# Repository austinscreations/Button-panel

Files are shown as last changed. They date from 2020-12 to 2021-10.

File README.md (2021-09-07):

# Button-panel
Low cost RGB button panel for home automation - based off superhouse.tv switch setup

After seeing the new RGB switch panels that jon from superhouse.tv is making the thing that has been noted is the switches cost a fair bit of money. 

I thought it might be possible to 3d print parts and use clear acrylic tubing / rod to create low cost versions of teh panels.
To start I've designed two PCB's one has 4 leds per button to emulate teh current ring light buttons
the second version uses one center led for a cenetr lighting in the button - acyrlic rod would be inserted into a 3d print.

Once I have a chance I plan to produce the pcb and order parts on ebay and create the 3d print assemblies to see what teh cost would be and if it works well.

2021-09-07
added a node-red demo taht hsows all the functions nicely.
added to and bottom photos of pcb along with pinout for RX / TX

2021-07-08
Working full code for type-1 assembly has been added. Now has working button deboucing and outputs teh same json type string as the superhouse.tv LSC project.
New PCB's has been produced and is working correctly with new code - files might need to be updated here...

2021-04-28
Added the latest version. will order parts soon to test the design.
Added a new 3d model for an AUS plate, design is incomplete and will get my hands on a real one to adjust the model as needed.

2021-04-23 
added code that will be used during livestream. haven't got tasmota to control the lights correctly yet; thus will be using custom code

2021-04-22
PCB's arrived which means I'll be doing a livestream of their assembly and testing https://youtu.be/Dpo3wsEXy4c

2021-04-18
Updated 3d files to fit around capacitors and ethernet connector. The 3d files and pcb's will be re-layed out to fix these in the next version. allowing for faster 3d printing, vs having holes / cutouts made.

2021-04-16
I've ordered PCB's to test. 
Created 3d photo of pcb assemblies. Next versions will use esp8266 direct vs D1 mini.
Cost Sheet updated.

2020-12-12
reformated files
added new version 2 which makes the pcb compact - allows for 24mm spacing between each button matching the assembly of teh superhouse button panels - it allso allowed for teh buttons to be centered on a wall plate. wall plate is normal cover / size for single gang north america box
3D step files for each button design assembly has been added - these are untested - no parts on order yet.
future possible version my have the 0.1mm pitch conenctor to match up to the new superhouse tv RGB button assembly.

2020-12-04
updating pcb files as the 1000uf capacitor was the wrong size (footprint is now 10x10mm)
adding photos of the pcb for both versions
added parts list for both versions
added rough cost breakdown of buying parts on ebay

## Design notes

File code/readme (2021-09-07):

code for v3 button panel

working code is available for type 1 button panel - has the ring lights
buttons and LEDs work on 1-based numbering.

MQTT information:
 *  option - set color    (topic = %hostname%/color; payload = led#, R,G,B,W (0-255))
 *  option fade to color  (topic = %hostname%/fade;  payload = led#, R,G,B,W (0-255))
 *  option ring           (topic = %hostname%/ring;  payload = led#, #ON, R,G,B,W (0-255))
 *  option FWD animation  (topic = %hostname%/fwd;   payload = led#, R,G,B,W,R2,G2,B2,W2,  (0-255))
 *  option BWD animation  (topic = %hostname%/bwd;   payload = led#, R,G,B,W,R2,G2,B2,W2,  (0-255))
 *
 *  button press = button # and state output on topic %hostname%/button
 *  
 *  online status can be found with %hostname%/LWT

node red demo will require node-red-contrib-countdown : countdown (there are two, i used the first one, non #2)

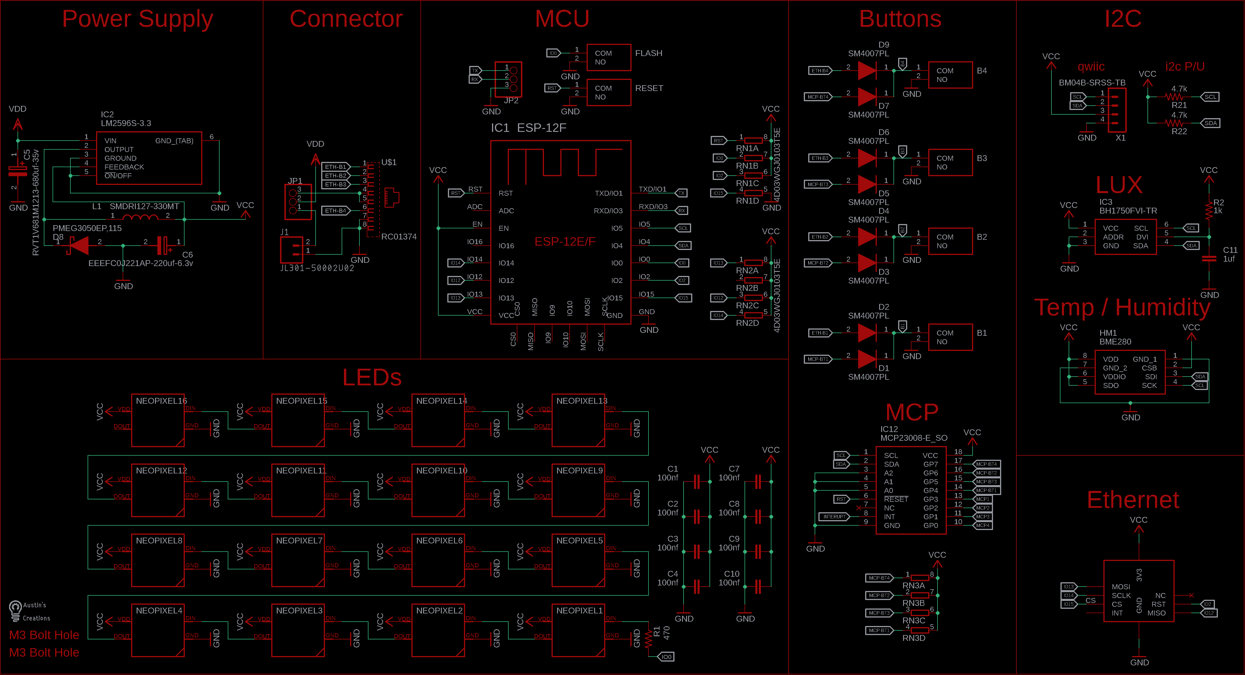
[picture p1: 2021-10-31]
version 4/type-1/schematic.png

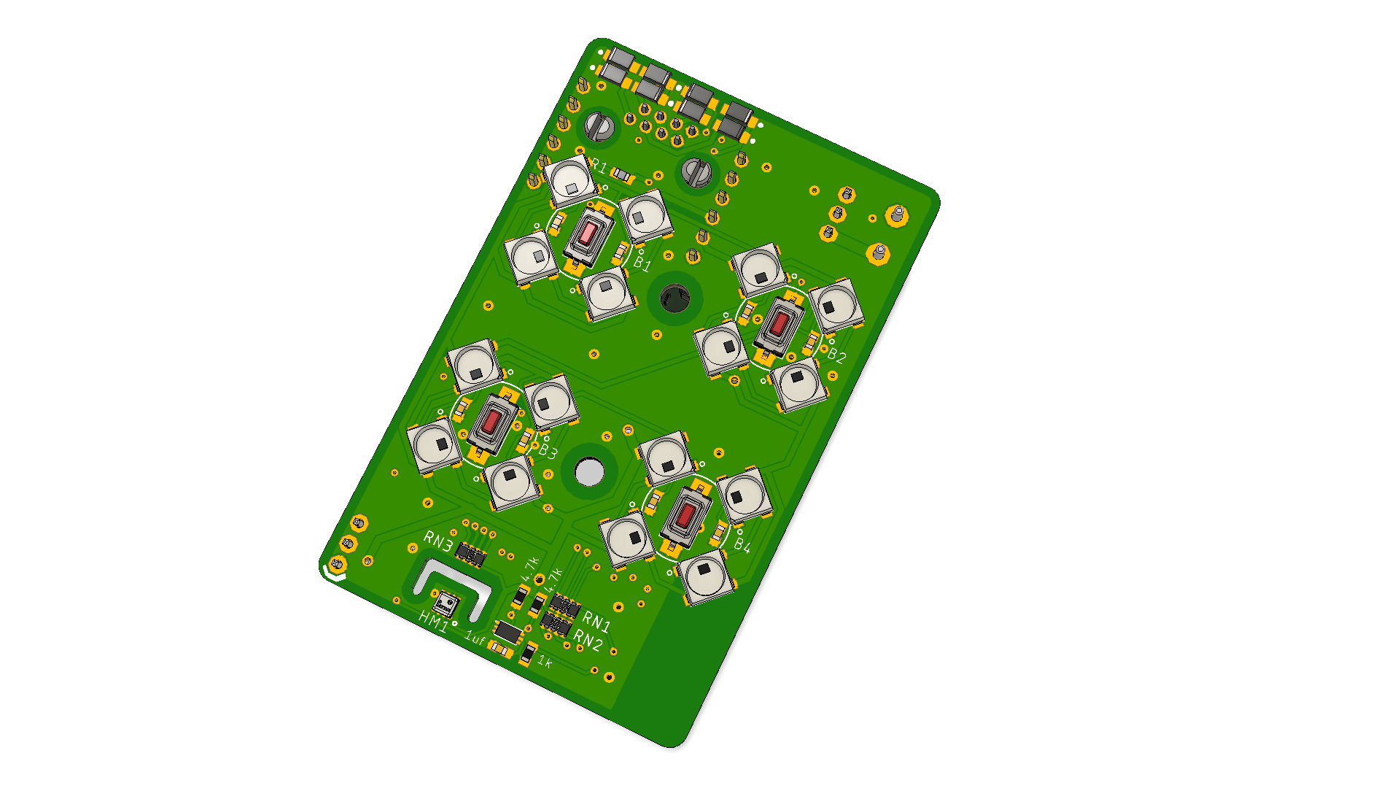
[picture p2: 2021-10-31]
version 4/type-1/smart switch front.png

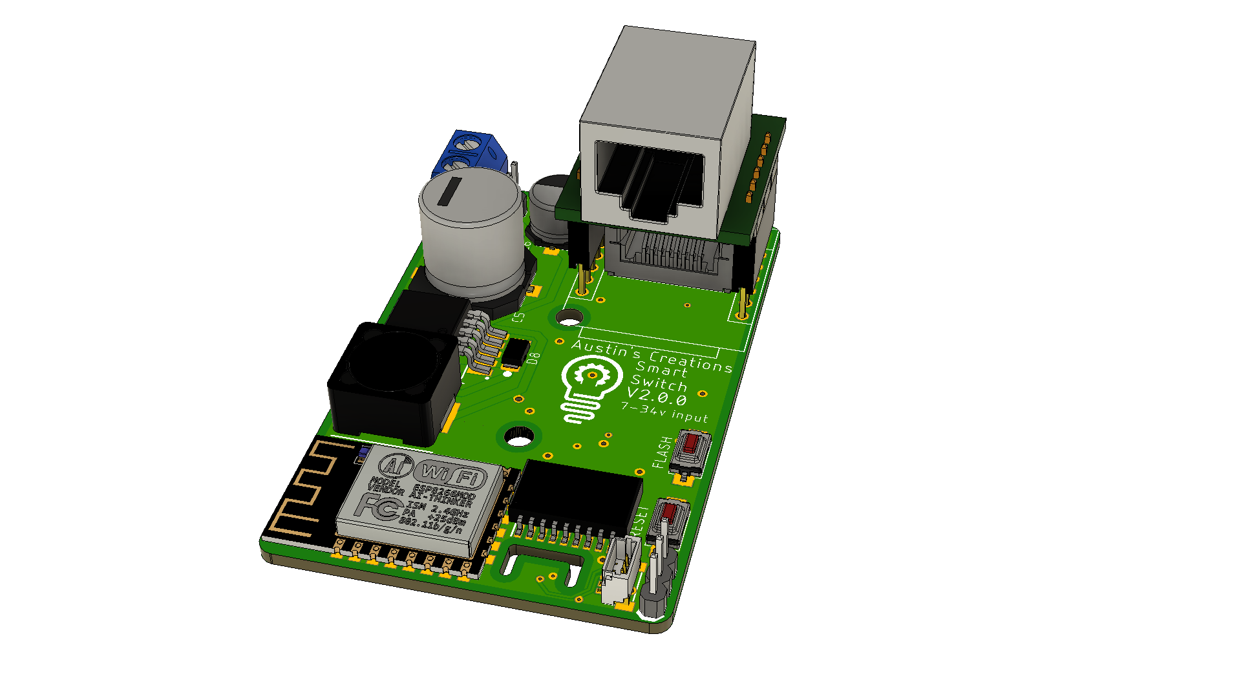
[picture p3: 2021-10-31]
version 4/type-1/smart switch back.png

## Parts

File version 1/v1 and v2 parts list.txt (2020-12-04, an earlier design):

# v1 4 button parts list

16x - RGBW sk6812 LED
1x  - molex 0446200001 RJ45 ethernet plug
1x  - wemos D1 mini
1x  - 0603 resistor 470ohm
5x  - 0603 SMD 0.1uf capacitor
1x  - 0603 10uf capcitor
1x  - 10x10mm 16v 1000uf capacitor EEE-FN1C102UL
1x  - AMS1117 3.3v
4x  - 6x3.5mm tactile switch PTS636SM25FSMTRLFS
1x  - 14mm od / 10mm id acrylic tubing

# v2 4 button parts list

4x  - RGBW sk6812 LED
1x  - molex 0446200001 RJ45 ethernet plug
1x  - 0603 resistor 470ohm
5x  - 0603 SMD 0.1uf capacitor
1x  - 0603 10uf capcitor
1x  - 10x10mm 16v 1000uf capacitor EEE-FN1C102UL
1x  - AMS1117 3.3v
8x  - 6x3.5mm tactile switch PTS636SM25FSMTRLFS
1x  - 3mm acrylic rod

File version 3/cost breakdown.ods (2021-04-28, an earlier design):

part | part numbers | needed | cost | qty | per item | total
V1 design
tubing acrylic | ebay | 1 | 38.02 | 60 | 0.6336666667 | 0.6336666667
bolts m3x8 | ebay | 2 | 5.71 | 100 | 0.0571 | 0.1142
thin jam nuts | ebay | 2 | 6.25 | 100 | 0.0625 | 0.125
led | ebay | 16 | 10.78 | 100 | 0.1078 | 1.7248
molex ethernet | C708627 Alt: C385834 | 1 | 11.43 | 100 | 0.1143 | 0.1143
470ohm resistor | C491171 | 1 | 5.66 | 100 | 0.0566 | 0.0566
10k resistor array | C29718 | 3 | 0.92 | 100 | 0.0092 | 0.0276
0.1uF cap | C83060 | 4 | 0.5 | 100 | 0.005 | 0.02
680uF 35v cap | C98216 | 1 | 38.47 | 100 | 0.3847 | 0.3847
220uF 6.3v cap | C401613 | 1 | 9.56 | 100 | 0.0956 | 0.0956
switch | C410373 | 6 | 5.35 | 100 | 0.0535 | 0.321
diode | C64898 | 8 | 0.98 | 100 | 0.0098 | 0.0784
diode | C50603 | 1 | 29.15 | 100 | 0.2915 | 0.2915
inductor 33uH | C9400 | 1 | 17.82 | 100 | 0.1782 | 0.1782
Regulator 3.3v | C347420 | 1 | 50.14 | 100 | 0.5014 | 0.5014
ESP-12F | C82891 | 1 | 18.46 | 10 | 1.846 | 1.846
screw terminal | C395214 | 1 | 9.75 | 150 | 0.065 | 0.065
TOTAL |  | 51 | 258.95 | 1620 |  | 6.58
V2 design
rod acrylic |  | 1 | 3.3 | 30 | 0.11 | 0.11
bolts m3x8 | ebay | 2 | 5.71 | 100 | 0.0571 | 0.1142
thin jam nuts | ebay | 2 | 6.25 | 100 | 0.0625 | 0.125
led | ebay | 4 | 10.78 | 100 | 0.1078 | 0.4312
molex ethernet | C708627 Alt: C385834 | 1 | 11.43 | 100 | 0.1143 | 0.1143
470ohm resistor | C491171 | 1 | 5.66 | 100 | 0.0566 | 0.0566
10k resistor array | C29718 | 3 | 0.92 | 100 | 0.0092 | 0.0276
0.1uF cap | C83060 | 4 | 0.5 | 100 | 0.005 | 0.02
680uF 35v cap | C98216 | 1 | 38.47 | 100 | 0.3847 | 0.3847
220uF 6.3v cap | C401613 | 1 | 9.56 | 100 | 0.0956 | 0.0956
switch | C410373 | 10 | 5.35 | 100 | 0.0535 | 0.535
diode | C64898 | 8 | 0.98 | 100 | 0.0098 | 0.0784
diode | C50603 | 1 | 29.15 | 100 | 0.2915 | 0.2915
inductor 33uH | C9400 | 1 | 17.82 | 100 | 0.1782 | 0.1782
Regulator 3.3v | C347420 | 1 | 50.14 | 100 | 0.5014 | 0.5014
ESP-12F | C82891 | 1 | 18.46 | 10 | 1.846 | 1.846
screw terminal | C395214 | 1 | 9.75 | 150 | 0.065 | 0.065
TOTAL |  | 29 | 180.18 | 960 |  | 4.19

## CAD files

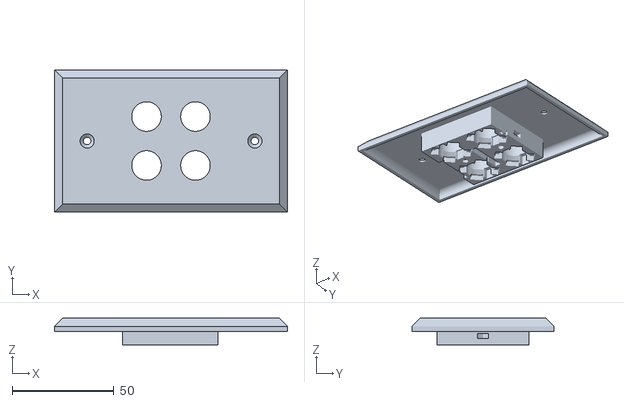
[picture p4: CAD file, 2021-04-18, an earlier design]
version 2/v1/4 button v1.stl
114.3 x 69.9 x 13.0

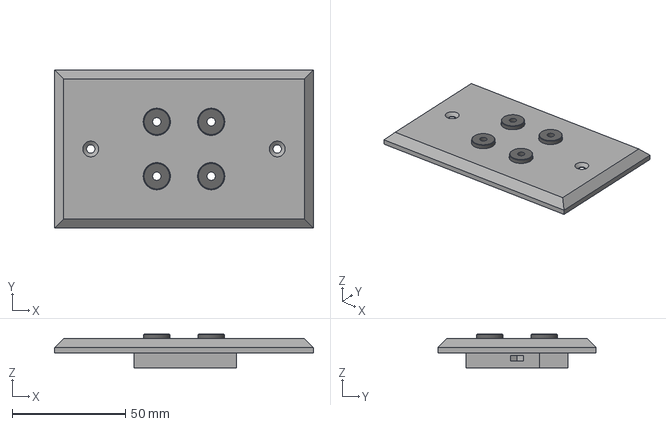
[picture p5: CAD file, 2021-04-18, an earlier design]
version 2/v2/4 button v4.step
114.3 x 69.8 x 15.0 mm

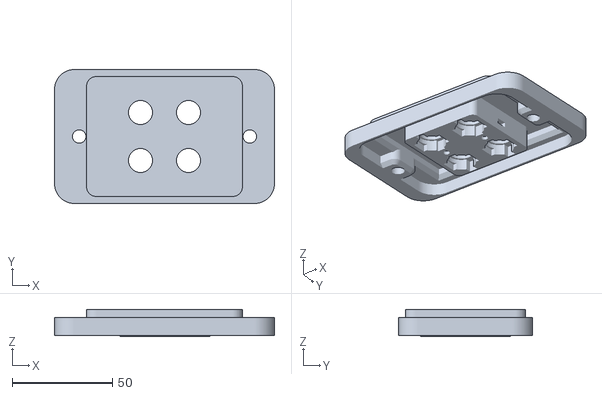
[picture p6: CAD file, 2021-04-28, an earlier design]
version 3/type-1/4 button type-2 AUS.stl
110.0 x 67.0 x 13.6

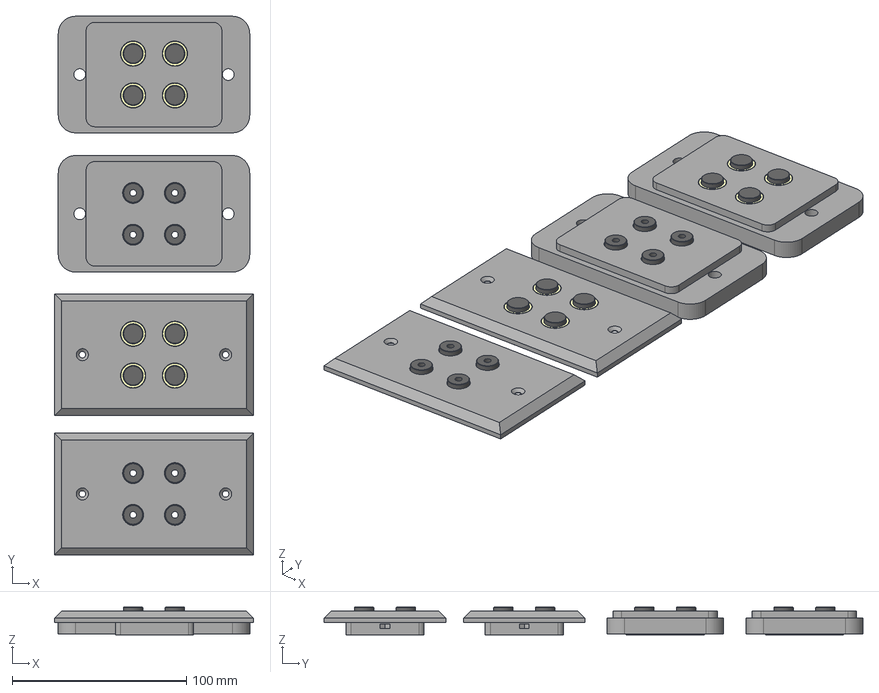
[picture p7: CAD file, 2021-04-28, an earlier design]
version 3/version 3.step
114.3 x 309.4 x 15.9 mm
type-1 NA
type-1 AUS
type-2 NA
type-2 AUS

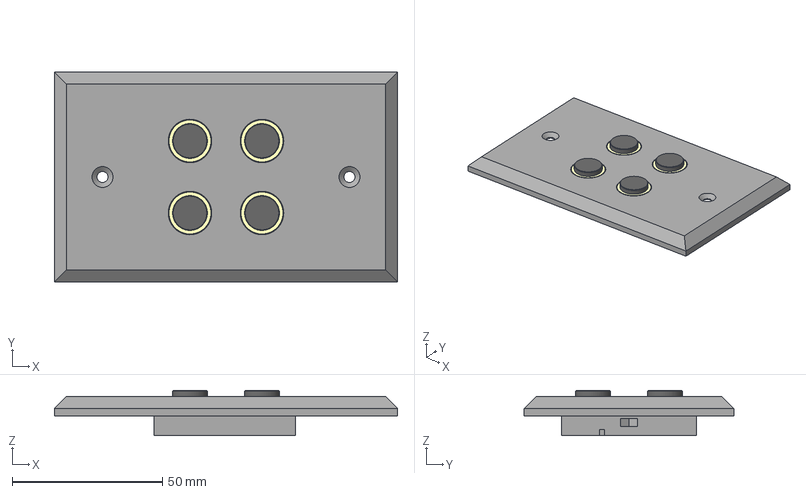
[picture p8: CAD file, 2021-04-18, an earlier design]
version 2/v1/4 button v3.step
114.3 x 69.8 x 15.0 mm
led v3
button v3

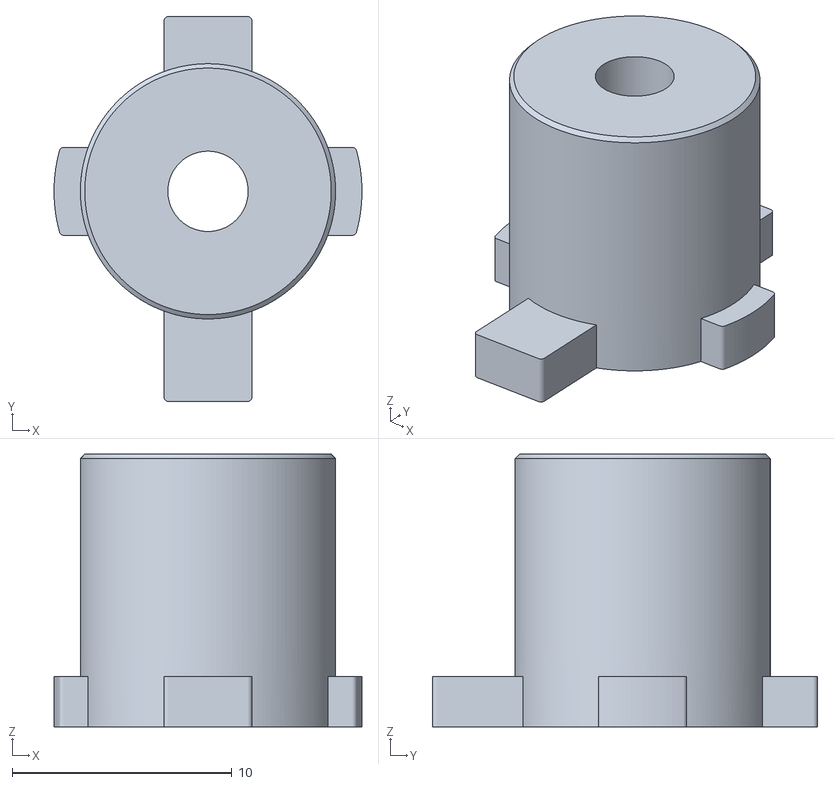
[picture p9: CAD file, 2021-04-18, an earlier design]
version 2/v2/button.stl
14.0 x 17.5 x 12.4

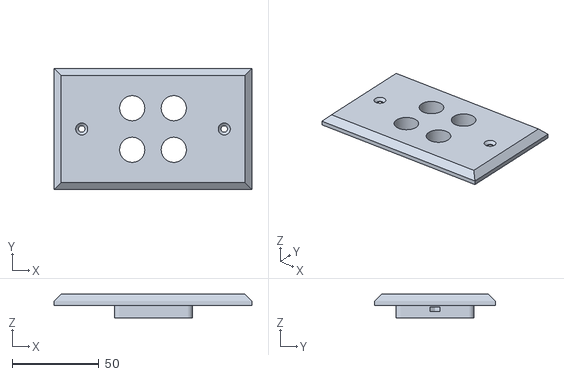
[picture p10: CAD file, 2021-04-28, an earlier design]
version 3/type-1/4 button type-1 NA.stl
114.3 x 69.8 x 13.6

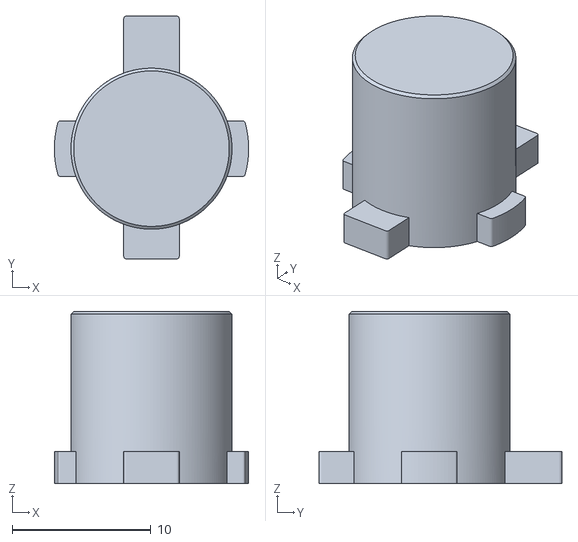
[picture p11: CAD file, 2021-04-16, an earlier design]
version 2/v1/button.stl
14.0 x 17.5 x 12.4

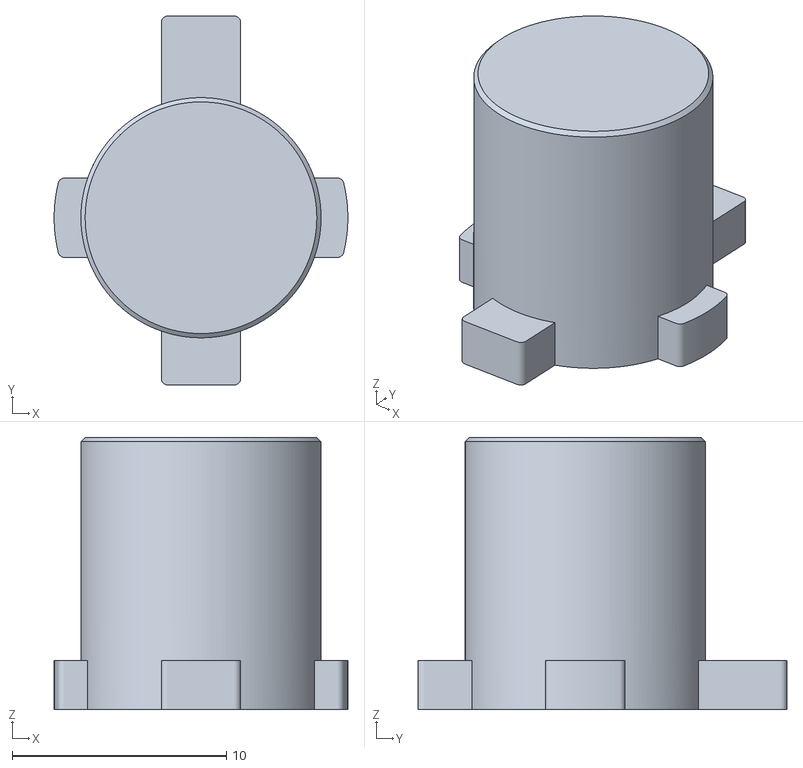
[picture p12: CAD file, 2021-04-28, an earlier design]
version 3/type-1/button.stl
13.7 x 17.2 x 12.7

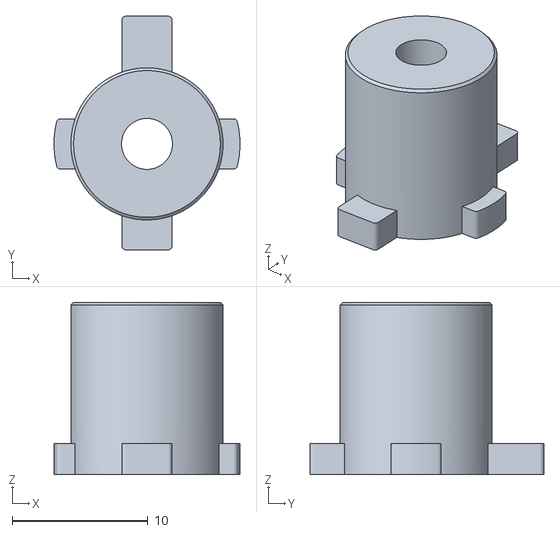
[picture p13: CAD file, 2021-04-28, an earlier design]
version 3/type-2/button.stl
13.7 x 17.2 x 12.7

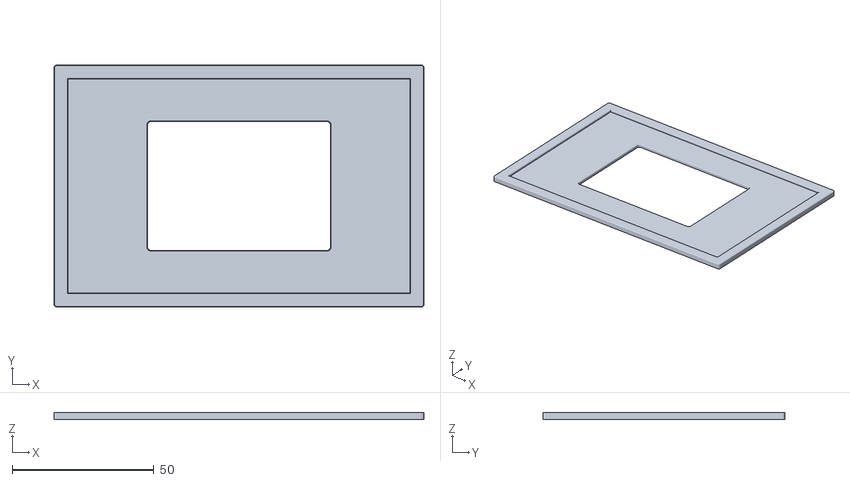
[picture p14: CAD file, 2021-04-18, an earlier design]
version 2/v2/pcb stencil holder.stl
130.3 x 85.3 x 2.60

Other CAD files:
version 2/v2/embroidered panels/v2 4 button demo.step
version 3/type-2/4 button type-2 NA.stl
version 2/v2/4 button v2.stl
version 2/v2/embroidered panels/v2 4 button demo.stl

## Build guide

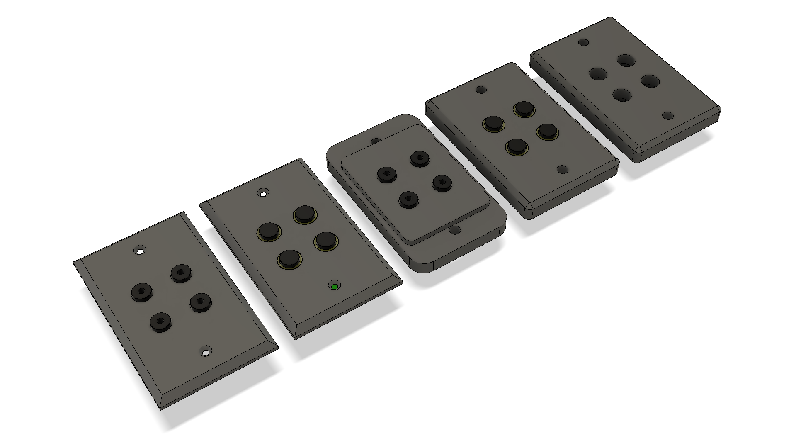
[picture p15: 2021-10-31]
version 4/type-1/3D printable assemblies.png

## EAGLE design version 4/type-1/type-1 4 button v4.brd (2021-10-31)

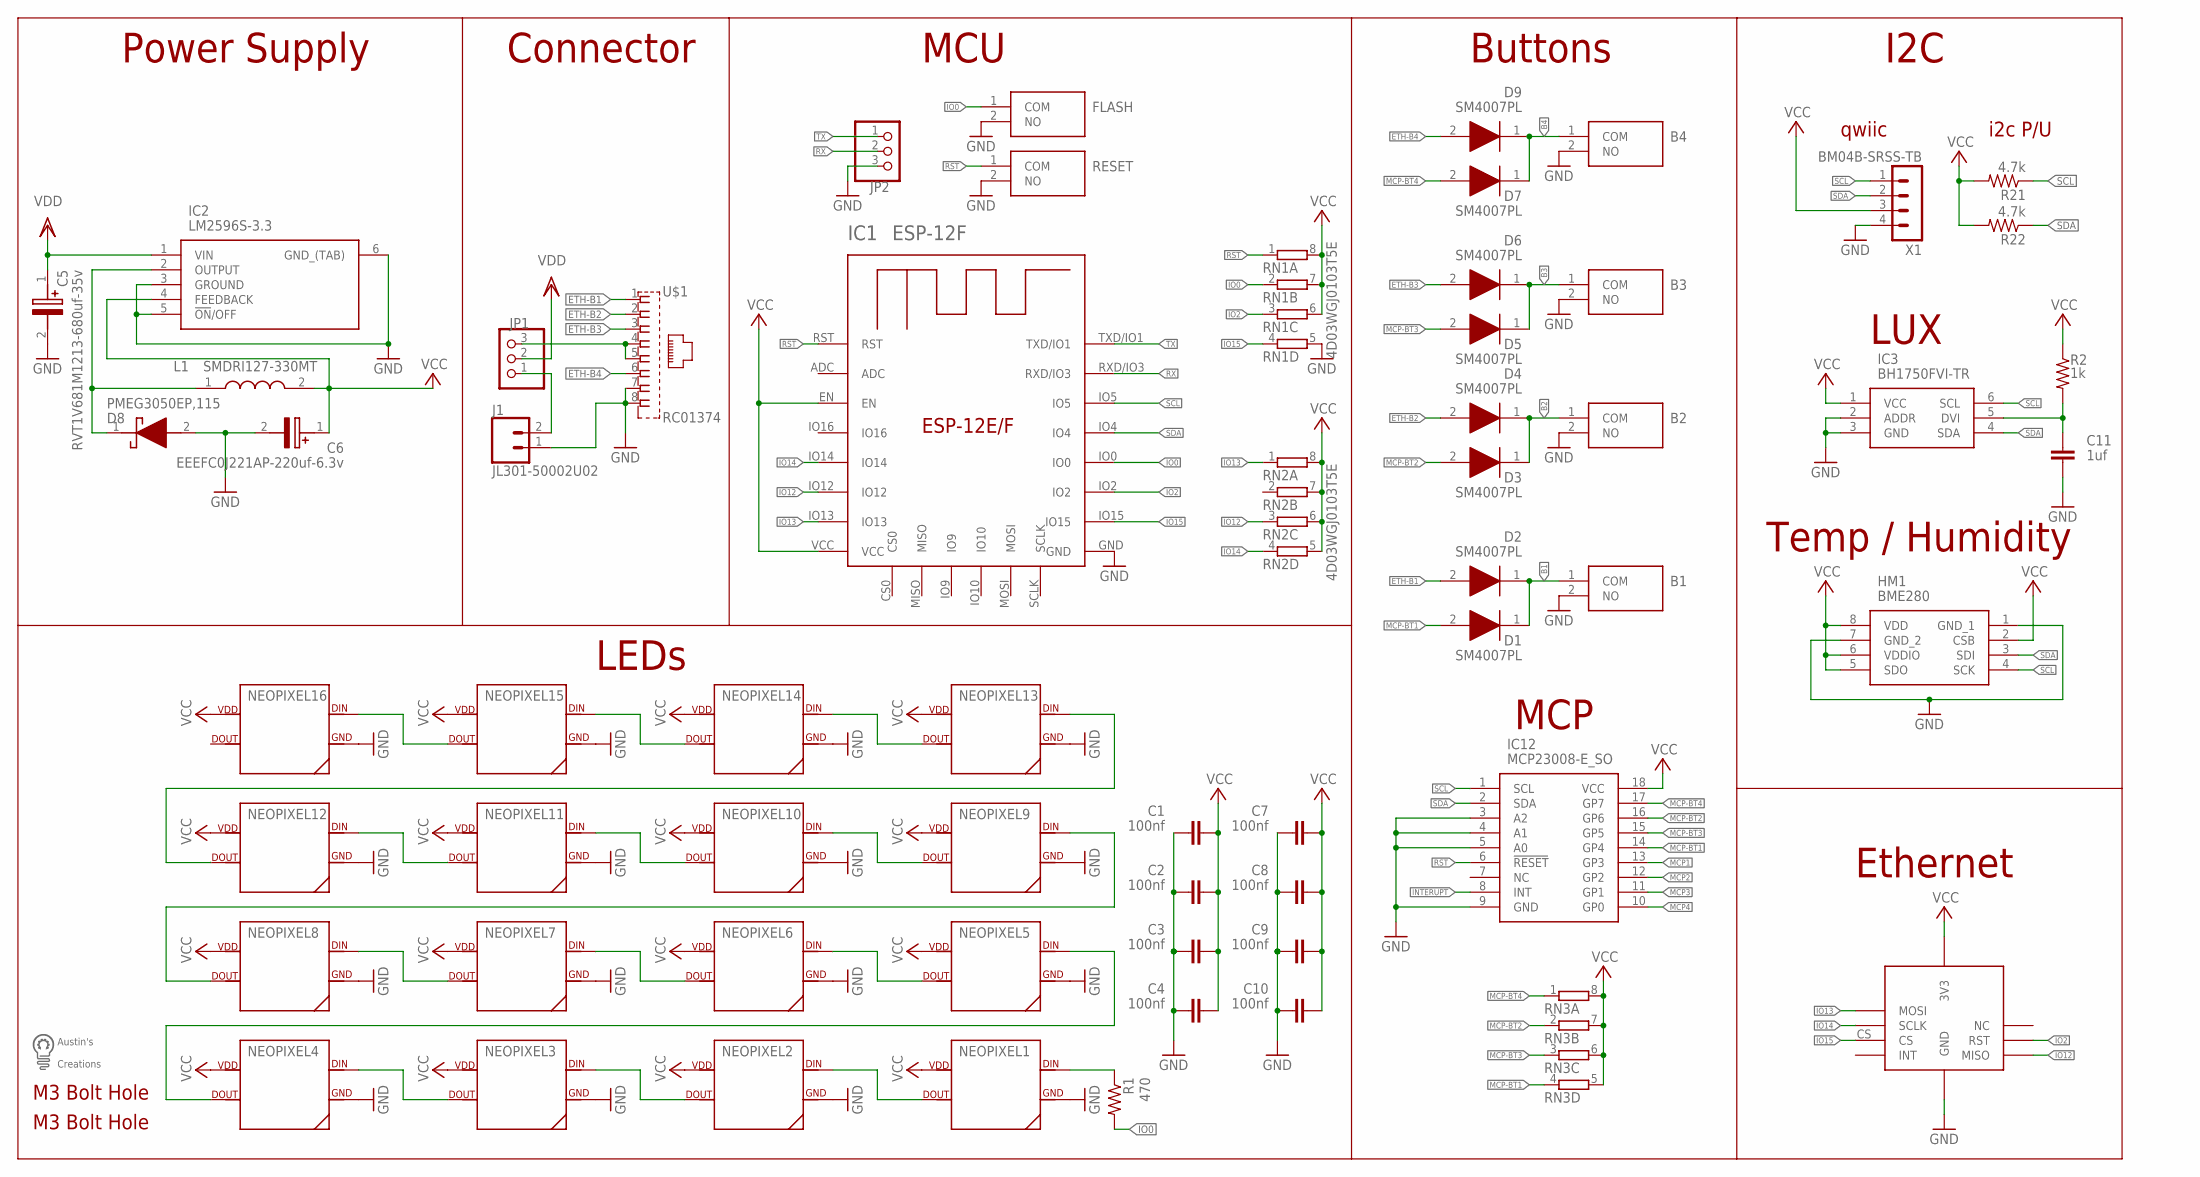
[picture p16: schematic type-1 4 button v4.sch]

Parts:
B1, B2, B3, B4: PTS636_SM25F_SMTR_LFS; PTS636SM25FSMTRLFS
C1, C2, C3, C4, C7, C8, C9, C10: 100nf; C0603
C5: RVT1V681M1213-680uf-35v; CAPAE1350X1400N
C6: EEEFC0J221AP-220uf-6.3v; CAPAE830X650N
C11: 1uf; C0603
D1, D2, D3, D4, D5, D6, D7, D9: SM4007PL; SODFL3718X125N
D8: PMEG3050EP,115; PMEG3050EP115
FLASH: PTS636_SM25F_SMTR_LFS; PTS636SM25FSMTRLFS
HM1: BME280
IC1: ESP-12F; ESP-12E
IC2: LM2596S-3.3; TO170P1435X465-6N
IC3: BH1750FVI-TR; WSOF6
IC12: MCP23008-E_SO; SOIC127P1030X265-18N
J1: JL301-50002U02; SCREWTERMINAL-5MM-2
JP1, JP2: PINHD-1X3; 1X03
L1: SMDRI127-330MT; INDPM120120X800N
NEOPIXEL1, NEOPIXEL2, NEOPIXEL3, NEOPIXEL4, NEOPIXEL5, NEOPIXEL6, NEOPIXEL7, NEOPIXEL8, NEOPIXEL9, NEOPIXEL10, NEOPIXEL11, NEOPIXEL12, NEOPIXEL13, NEOPIXEL14, NEOPIXEL15, NEOPIXEL16: SK6812NEOPIXEL5050; SK6812
R1: 470; R0603
R2: 1k; R0603
R21, R22: 4.7k; R0603
RESET: PTS636_SM25F_SMTR_LFS; PTS636SM25FSMTRLFS
RN1, RN2, RN3: 4R-N0603-ARC; 0603-ARC
U$1: RC01374
U$3: W5500MODULE
U$4, U$5: M3BOLTHOLE
U$6: LOGOMED
X1: BM04B-SRSS-TB

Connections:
B1: B1.1 (COM), D1.1 (K), D2.1 (K)
B2: B2.1 (COM), D3.1 (K), D4.1 (K)
B3: B3.1 (COM), D5.1 (K), D6.1 (K)
B4: B4.1 (COM), D7.1 (K), D9.1 (K)
ETH-B1: D2.2 (A), U$1.1
ETH-B2: D4.2 (A), U$1.2
ETH-B3: D6.2 (A), U$1.3
ETH-B4: D9.2 (A), U$1.6
GND: B1.2 (NO), B2.2 (NO), B3.2 (NO), B4.2 (NO), C1.1, C2.1, C3.1, C4.1, C5.2 (-), C6.2 (-), C7.1, C8.1, C9.1, C10.1, C11.2, D8.2 (A), FLASH.2 (NO), HM1.1 (GND_1), HM1.7 (GND_2), IC1.GND, IC2.3 (GROUND), IC2.5 (!ON!/OFF), IC2.6 (GND_(TAB)), IC3.2 (ADDR), IC3.3 (GND), IC12.3 (A2), IC12.4 (A1), IC12.5 (A0), IC12.9 (GND), J1.1, JP2.3, NEOPIXEL1.3 (GND), NEOPIXEL2.3 (GND), NEOPIXEL3.3 (GND), NEOPIXEL4.3 (GND), NEOPIXEL5.3 (GND), NEOPIXEL6.3 (GND), NEOPIXEL7.3 (GND), NEOPIXEL8.3 (GND), NEOPIXEL9.3 (GND), NEOPIXEL10.3 (GND), NEOPIXEL11.3 (GND), NEOPIXEL12.3 (GND), NEOPIXEL13.3 (GND), NEOPIXEL14.3 (GND), NEOPIXEL15.3 (GND), NEOPIXEL16.3 (GND), RESET.2 (NO), RN1.5 (2), U$1.7, U$1.8, U$3.GND1 (GND), U$3.GND2 (GND), U$3.GND3 (GND), X1.4
INTERUPT: IC12.8 (INT)
IO0: FLASH.1 (COM), IC1.IO0, R1.2, RN1.2 (1)
IO2: IC1.IO2, RN1.3 (1), U$3.RST
IO12: IC1.IO12, RN2.3 (1), U$3.MISO
IO13: IC1.IO13, RN2.1, U$3.MOSI
IO14: IC1.IO14, RN2.4 (1), U$3.SCLK
IO15: IC1.IO15, RN1.4 (1), U$3.CS
MCP1: IC12.13 (GP3)
MCP2: IC12.12 (GP2)
MCP3: IC12.11 (GP1)
MCP4: IC12.10 (GP0)
MCP-BT1: D1.2 (A), IC12.14 (GP4), RN3.4 (1)
MCP-BT2: D3.2 (A), IC12.16 (GP6), RN3.2 (1)
MCP-BT3: D5.2 (A), IC12.15 (GP5), RN3.3 (1)
MCP-BT4: D7.2 (A), IC12.17 (GP7), RN3.1
unnamed: NEOPIXEL1.4 (DIN), R1.1
unnamed: NEOPIXEL1.2 (DOUT), NEOPIXEL2.4 (DIN)
unnamed: NEOPIXEL2.2 (DOUT), NEOPIXEL3.4 (DIN)
unnamed: NEOPIXEL3.2 (DOUT), NEOPIXEL4.4 (DIN)
unnamed: NEOPIXEL4.2 (DOUT), NEOPIXEL5.4 (DIN)
unnamed: NEOPIXEL8.2 (DOUT), NEOPIXEL9.4 (DIN)
unnamed: NEOPIXEL12.2 (DOUT), NEOPIXEL13.4 (DIN)
unnamed: NEOPIXEL5.2 (DOUT), NEOPIXEL6.4 (DIN)
unnamed: NEOPIXEL9.2 (DOUT), NEOPIXEL10.4 (DIN)
unnamed: NEOPIXEL13.2 (DOUT), NEOPIXEL14.4 (DIN)
unnamed: NEOPIXEL6.2 (DOUT), NEOPIXEL7.4 (DIN)
unnamed: NEOPIXEL10.2 (DOUT), NEOPIXEL11.4 (DIN)
unnamed: NEOPIXEL14.2 (DOUT), NEOPIXEL15.4 (DIN)
unnamed: NEOPIXEL7.2 (DOUT), NEOPIXEL8.4 (DIN)
unnamed: NEOPIXEL11.2 (DOUT), NEOPIXEL12.4 (DIN)
unnamed: NEOPIXEL15.2 (DOUT), NEOPIXEL16.4 (DIN)
unnamed: JP1.3, U$1.4, U$1.5
unnamed: J1.2, JP1.1
unnamed: D8.1 (K), IC2.2 (OUTPUT), L1.1
unnamed: C11.1, IC3.5 (DVI), R2.2
RST: IC1.RST, IC12.6 (!RESET), RESET.1 (COM), RN1.1
RX: IC1.RXD/IO3, JP2.2
SCL: HM1.4 (SCK), IC1.IO5, IC3.6 (SCL), IC12.1 (SCL), R21.1, X1.1
SDA: HM1.3 (SDI), IC1.IO4, IC3.4 (SDA), IC12.2 (SDA), R22.1, X1.2
TX: IC1.TXD/IO1, JP2.1
VCC: C1.2, C2.2, C3.2, C4.2, C6.1 (+), C7.2, C8.2, C9.2, C10.2, HM1.2 (CSB), HM1.5 (SDO), HM1.6 (VDDIO), HM1.8 (VDD), IC1.EN, IC1.VCC, IC2.4 (FEEDBACK), IC3.1 (VCC), IC12.18 (VCC), L1.2, NEOPIXEL1.1 (VDD), NEOPIXEL2.1 (VDD), NEOPIXEL3.1 (VDD), NEOPIXEL4.1 (VDD), NEOPIXEL5.1 (VDD), NEOPIXEL6.1 (VDD), NEOPIXEL7.1 (VDD), NEOPIXEL8.1 (VDD), NEOPIXEL9.1 (VDD), NEOPIXEL10.1 (VDD), NEOPIXEL11.1 (VDD), NEOPIXEL12.1 (VDD), NEOPIXEL13.1 (VDD), NEOPIXEL14.1 (VDD), NEOPIXEL15.1 (VDD), NEOPIXEL16.1 (VDD), R2.1, R21.2, R22.2, RN1.6 (2), RN1.7 (2), RN1.8 (2), RN2.5 (2), RN2.6 (2), RN2.7 (2), RN2.8 (2), RN3.5 (2), RN3.6 (2), RN3.7 (2), RN3.8 (2), U$3.3V3_1 (3V3), U$3.3V3_2 (3V3), X1.3
VDD: C5.1 (+), IC2.1 (VIN), JP1.2

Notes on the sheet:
Buttons
MCU
Connector
Power Supply
LEDs
4D03WGJ0103T5E
MCP
Ethernet
Temp / Humidity
LUX
i2c P/U
I2C
qwiic

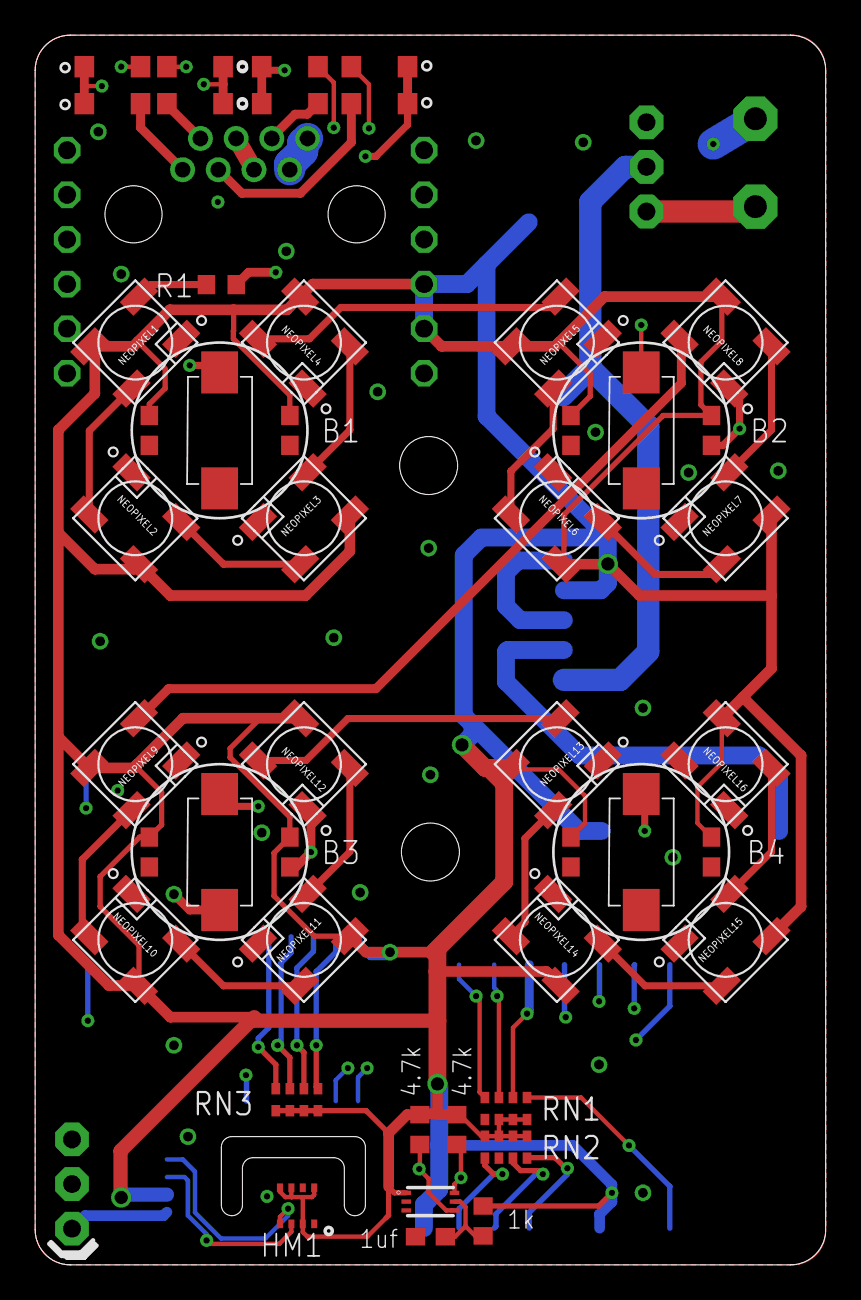
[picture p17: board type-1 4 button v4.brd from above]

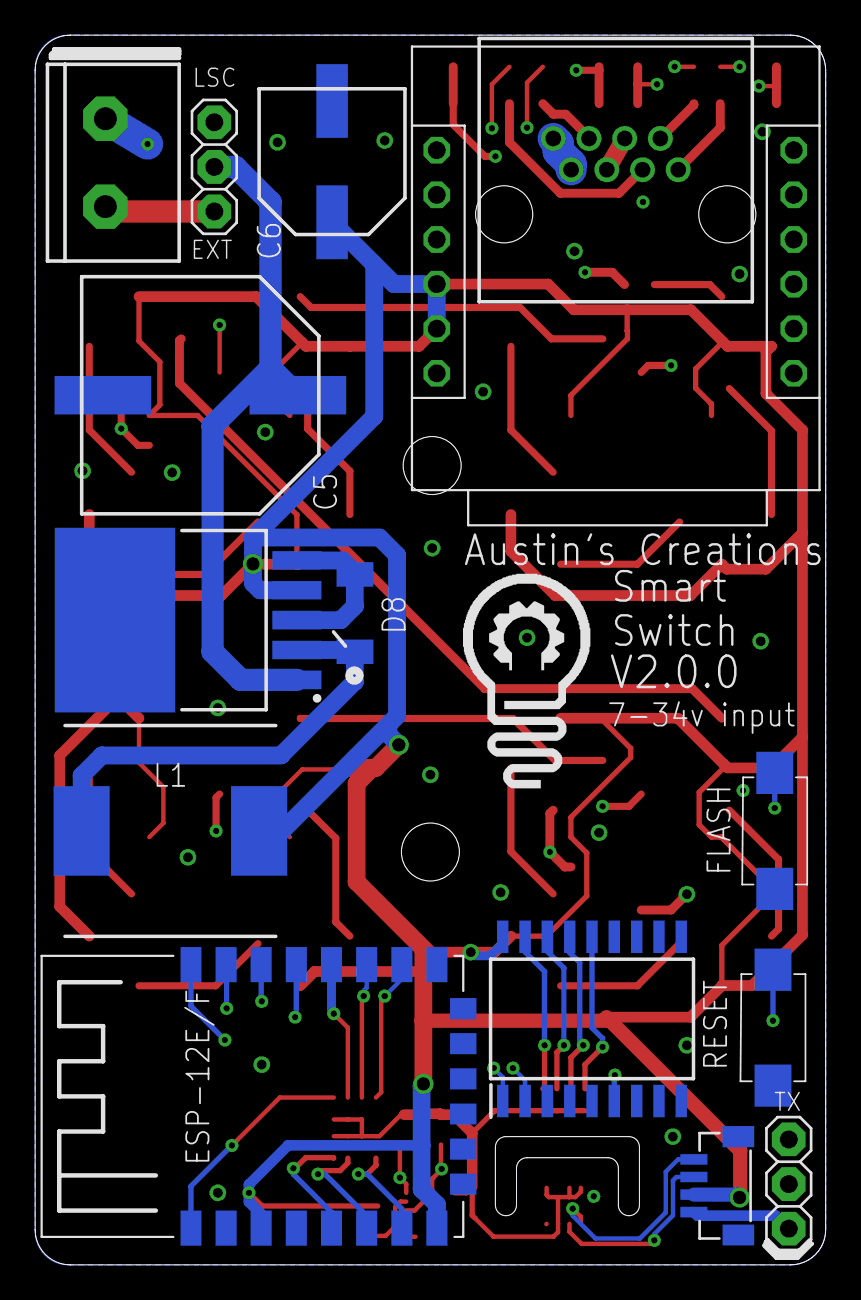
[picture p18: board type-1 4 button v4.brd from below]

Board: 4 copper layers, 45.0 x 70.0 mm, 64 parts (16 on the bottom side), 46 nets.

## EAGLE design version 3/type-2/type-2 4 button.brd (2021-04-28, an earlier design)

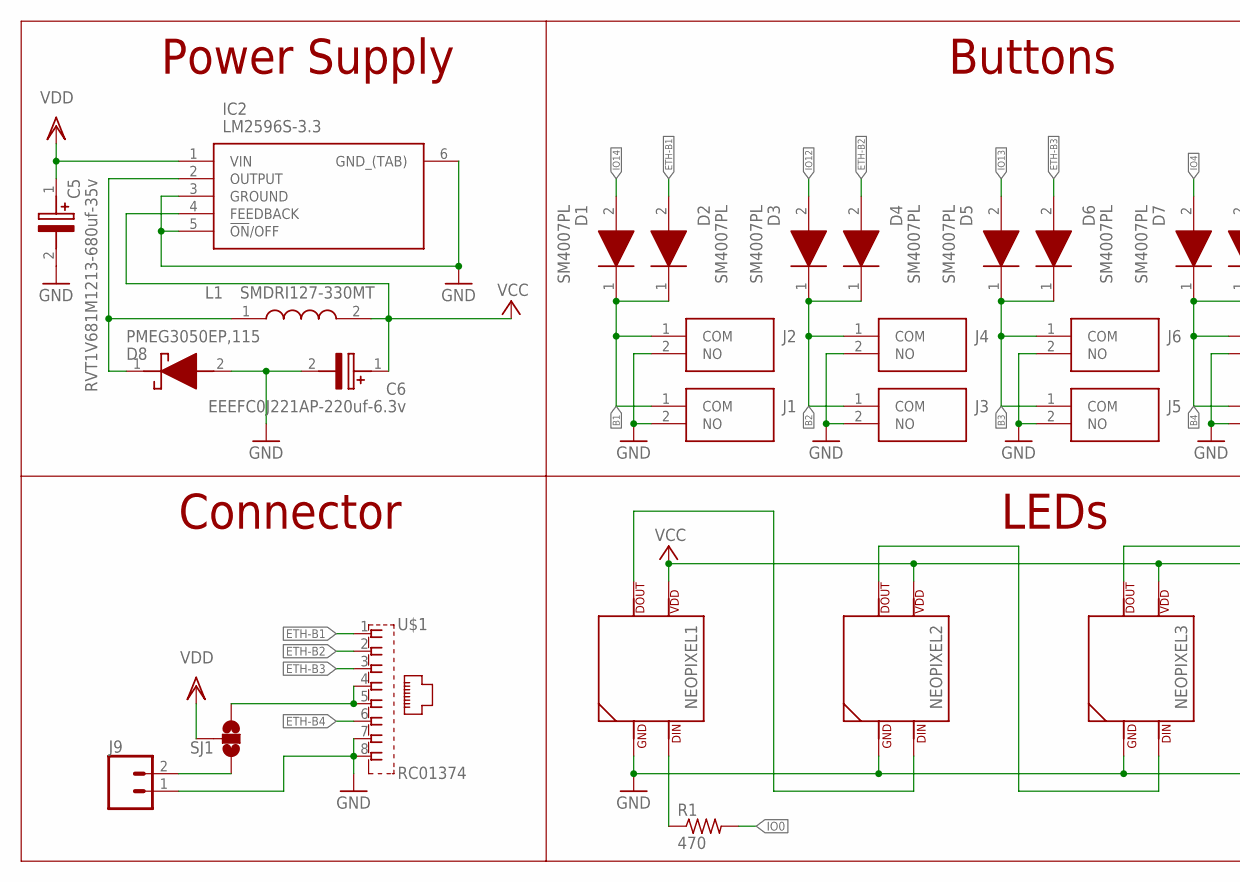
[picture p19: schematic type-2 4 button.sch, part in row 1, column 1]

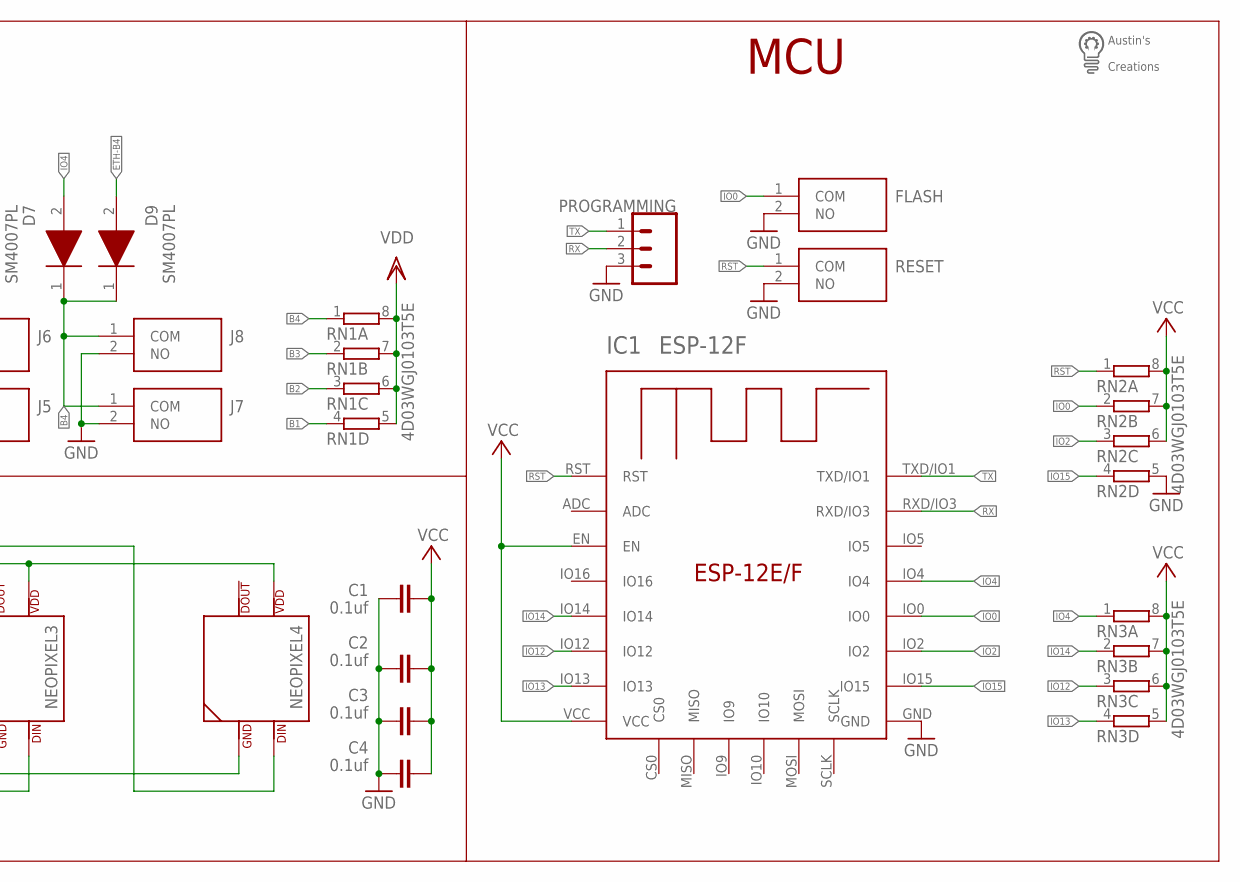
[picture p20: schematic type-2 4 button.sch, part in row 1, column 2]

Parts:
C1, C2, C3, C4: 0.1uf; C0603
C5: RVT1V681M1213-680uf-35v; CAPAE1350X1400N
C6: EEEFC0J221AP-220uf-6.3v; CAPAE830X650N
D1, D2, D3, D4, D5, D6, D7, D9: SM4007PL; SODFL3718X125N
D8: PMEG3050EP,115; PMEG3050EP115
FLASH: PTS636_SM25F_SMTR_LFS; PTS636SM25FSMTRLFS
IC1: ESP-12F; ESP-12E
IC2: LM2596S-3.3; TO170P1435X465-6N
J1, J2, J3, J4, J5, J6, J7, J8: PTS636_SM25F_SMTR_LFS; PTS636SM25FSMTRLFS
J9: CONN_025MM; SCREWTERMINAL-5MM-2
L1: SMDRI127-330MT; INDPM120120X800N
NEOPIXEL1, NEOPIXEL2, NEOPIXEL3, NEOPIXEL4: SK6812NEOPIXEL5050; SK6812
PROGRAMMING: 455-1750-1-ND; 1X03
R1: 470; R0603
RESET: PTS636_SM25F_SMTR_LFS; PTS636SM25FSMTRLFS
RN1, RN2, RN3: 4R-N0603-ARC; 0603-ARC
SJ1: SOLDERJUMPER_2WAYPASTE1&2; SJ_3_PASTE1&2
U$1: RC01374
U$2: LOGO

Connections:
B1: D1.1 (K), D2.1 (K), J1.1 (COM), J2.1 (COM), RN1.4 (1)
B2: D3.1 (K), D4.1 (K), J3.1 (COM), J4.1 (COM), RN1.3 (1)
B3: D5.1 (K), D6.1 (K), J5.1 (COM), J6.1 (COM), RN1.2 (1)
B4: D7.1 (K), D9.1 (K), J7.1 (COM), J8.1 (COM), RN1.1
ETH-B1: D2.2 (A), U$1.1
ETH-B2: D4.2 (A), U$1.2
ETH-B3: D6.2 (A), U$1.3
ETH-B4: D9.2 (A), U$1.6
GND: C1.1, C2.1, C3.1, C4.1, C5.2 (-), C6.2 (-), D8.2 (A), FLASH.2 (NO), IC1.GND, IC2.3 (GROUND), IC2.5 (!ON!/OFF), IC2.6 (GND_(TAB)), J1.2 (NO), J2.2 (NO), J3.2 (NO), J4.2 (NO), J5.2 (NO), J6.2 (NO), J7.2 (NO), J8.2 (NO), J9.1, NEOPIXEL1.3 (GND), NEOPIXEL2.3 (GND), NEOPIXEL3.3 (GND), NEOPIXEL4.3 (GND), PROGRAMMING.3, RESET.2 (NO), RN2.5 (2), U$1.7, U$1.8
IO0: FLASH.1 (COM), IC1.IO0, R1.2, RN2.2 (1)
IO2: IC1.IO2, RN2.3 (1)
IO4: D7.2 (A), IC1.IO4, RN3.1
IO12: D3.2 (A), IC1.IO12, RN3.3 (1)
IO13: D5.2 (A), IC1.IO13, RN3.4 (1)
IO14: D1.2 (A), IC1.IO14, RN3.2 (1)
IO15: IC1.IO15, RN2.4 (1)
unnamed: NEOPIXEL1.2 (DOUT), NEOPIXEL2.4 (DIN)
unnamed: NEOPIXEL2.2 (DOUT), NEOPIXEL3.4 (DIN)
unnamed: NEOPIXEL3.2 (DOUT), NEOPIXEL4.4 (DIN)
unnamed: NEOPIXEL1.4 (DIN), R1.1
unnamed: J9.2, SJ1.3
unnamed: SJ1.1, U$1.4, U$1.5
unnamed: D8.1 (K), IC2.2 (OUTPUT), L1.1
RST: IC1.RST, RESET.1 (COM), RN2.1
RX: IC1.RXD/IO3, PROGRAMMING.2
TX: IC1.TXD/IO1, PROGRAMMING.1
VCC: C1.2, C2.2, C3.2, C4.2, C6.1 (+), IC1.EN, IC1.VCC, IC2.4 (FEEDBACK), L1.2, NEOPIXEL1.1 (VDD), NEOPIXEL2.1 (VDD), NEOPIXEL3.1 (VDD), NEOPIXEL4.1 (VDD), RN2.6 (2), RN2.7 (2), RN2.8 (2), RN3.5 (2), RN3.6 (2), RN3.7 (2), RN3.8 (2)
VDD: C5.1 (+), IC2.1 (VIN), RN1.5 (2), RN1.6 (2), RN1.7 (2), RN1.8 (2), SJ1.2

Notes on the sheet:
Buttons
LEDs
Connector
MCU
Power Supply
4D03WGJ0103T5E

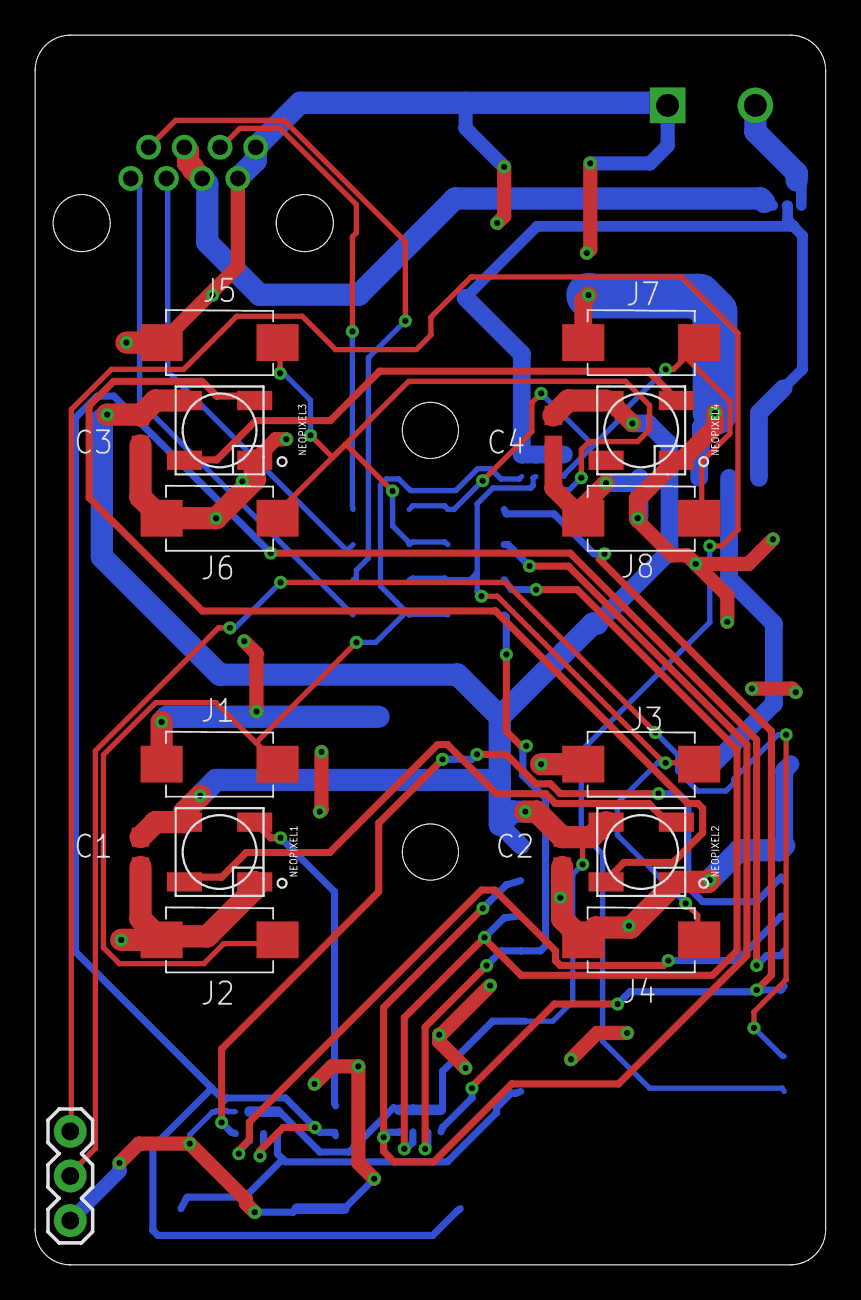
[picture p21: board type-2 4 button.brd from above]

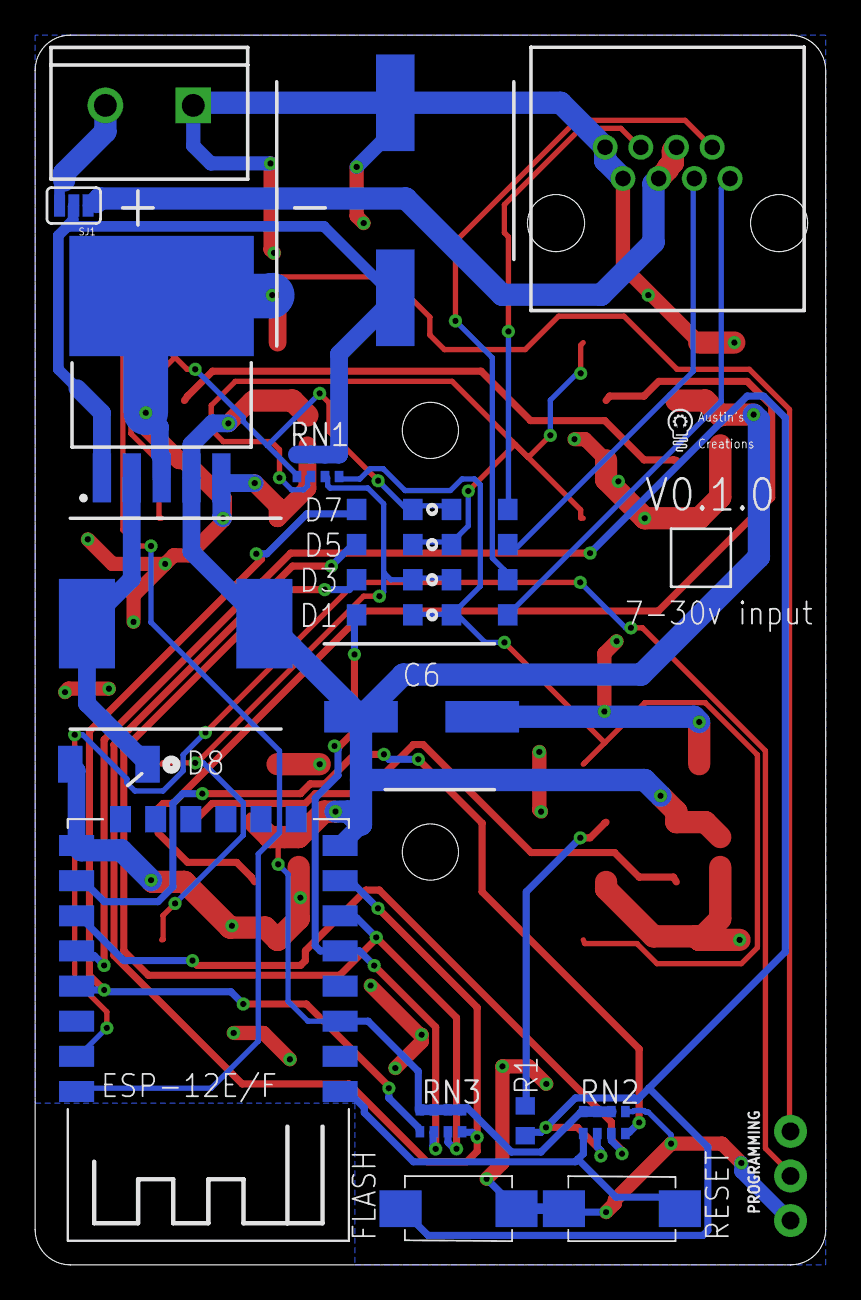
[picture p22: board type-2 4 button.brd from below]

Board: 2 copper layers, 45.0 x 70.0 mm, 41 parts (24 on the bottom side), 28 nets.

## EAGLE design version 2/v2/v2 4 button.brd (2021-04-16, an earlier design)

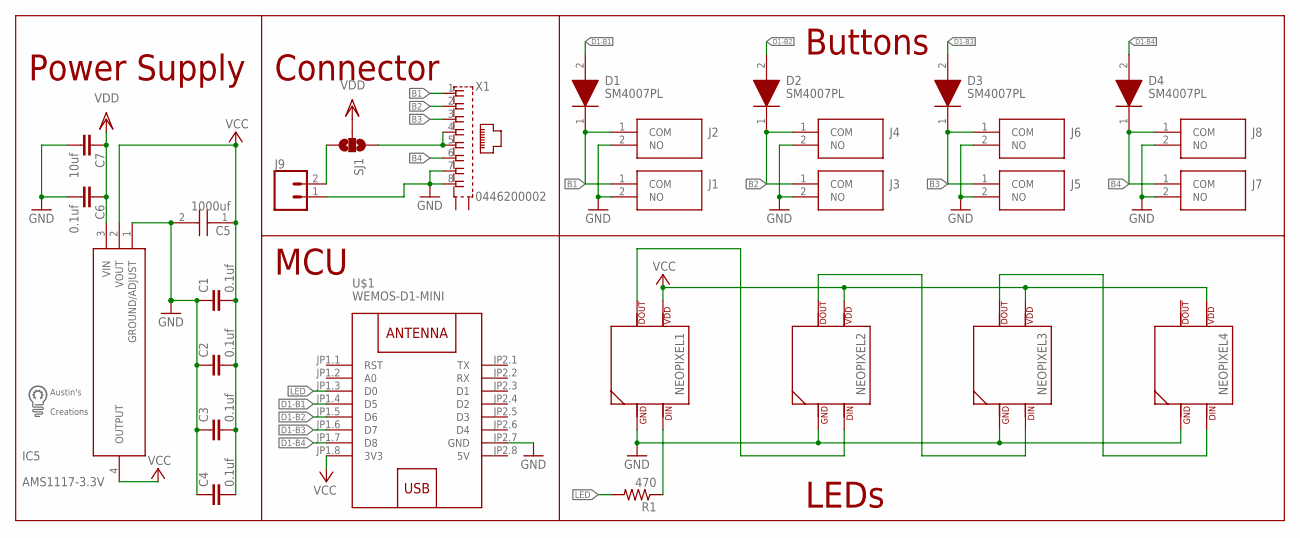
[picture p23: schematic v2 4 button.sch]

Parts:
C1, C2, C3, C4, C6: 0.1uf; C0603
C5: 1000uf; CAPAE1030X1050N
C7: 10uf; C0603
D1, D2, D3, D4: SM4007PL; SODFL3718X125N
IC5: AMS1117-3.3V; SOT229P700X180-4N
J1, J2, J3, J4, J5, J6, J7, J8: PTS636_SM25F_SMTR_LFS; PTS636SM25FSMTRLFS
J9: CONN_025MM; SCREWTERMINAL-5MM-2
NEOPIXEL1, NEOPIXEL2, NEOPIXEL3, NEOPIXEL4: SK6812NEOPIXEL5050; SK6812
R1: 470; R0603
SJ1: SOLDERJUMPER_2WAYPASTE1&2; SJ_3_PASTE1&2
U$1: WEMOS-D1-MINI
U$2: LOGO
X1: 0446200002

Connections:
5V: U$1.JP2.8 (5V)
B1: D1.1 (K), J1.1 (COM), J2.1 (COM), X1.1
B2: D2.1 (K), J3.1 (COM), J4.1 (COM), X1.2
B3: D3.1 (K), J5.1 (COM), J6.1 (COM), X1.3
B4: D4.1 (K), J7.1 (COM), J8.1 (COM), X1.6
D1-B1: D1.2 (A), U$1.JP1.4 (D5)
D1-B2: D2.2 (A), U$1.JP1.5 (D6)
D1-B3: D3.2 (A), U$1.JP1.6 (D7)
D1-B4: D4.2 (A), U$1.JP1.7 (D8)
GND: C1.1, C2.1, C3.1, C4.1, C5.2 (-), C6.2, C7.2, IC5.1 (GROUND/ADJUST), J1.2 (NO), J2.2 (NO), J3.2 (NO), J4.2 (NO), J5.2 (NO), J6.2 (NO), J7.2 (NO), J8.2 (NO), J9.1, NEOPIXEL1.3 (GND), NEOPIXEL2.3 (GND), NEOPIXEL3.3 (GND), NEOPIXEL4.3 (GND), U$1.JP2.7 (GND), X1.7, X1.8
LED: R1.2, U$1.JP1.3 (D0)
unnamed: NEOPIXEL1.2 (DOUT), NEOPIXEL2.4 (DIN)
unnamed: NEOPIXEL2.2 (DOUT), NEOPIXEL3.4 (DIN)
unnamed: NEOPIXEL3.2 (DOUT), NEOPIXEL4.4 (DIN)
unnamed: SJ1.1, X1.4, X1.5
unnamed: NEOPIXEL1.4 (DIN), R1.1
unnamed: J9.2, SJ1.3
VCC: C1.2, C2.2, C3.2, C4.2, C5.1 (+), IC5.2 (VOUT), IC5.4 (OUTPUT), NEOPIXEL1.1 (VDD), NEOPIXEL2.1 (VDD), NEOPIXEL3.1 (VDD), NEOPIXEL4.1 (VDD), U$1.JP1.8 (3V3)
VDD: C6.1, C7.1, IC5.3 (VIN), SJ1.2

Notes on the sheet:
Buttons
LEDs
Connector
MCU
Power Supply

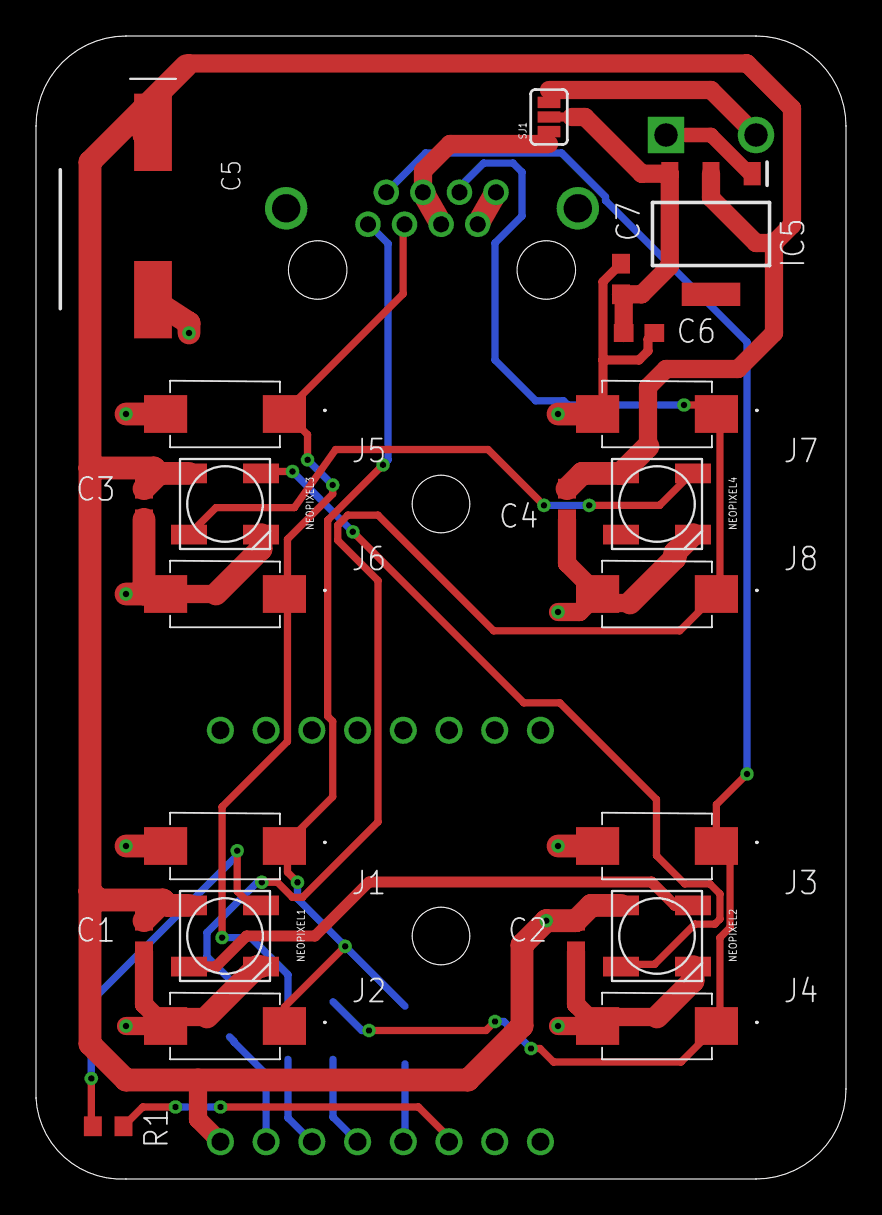
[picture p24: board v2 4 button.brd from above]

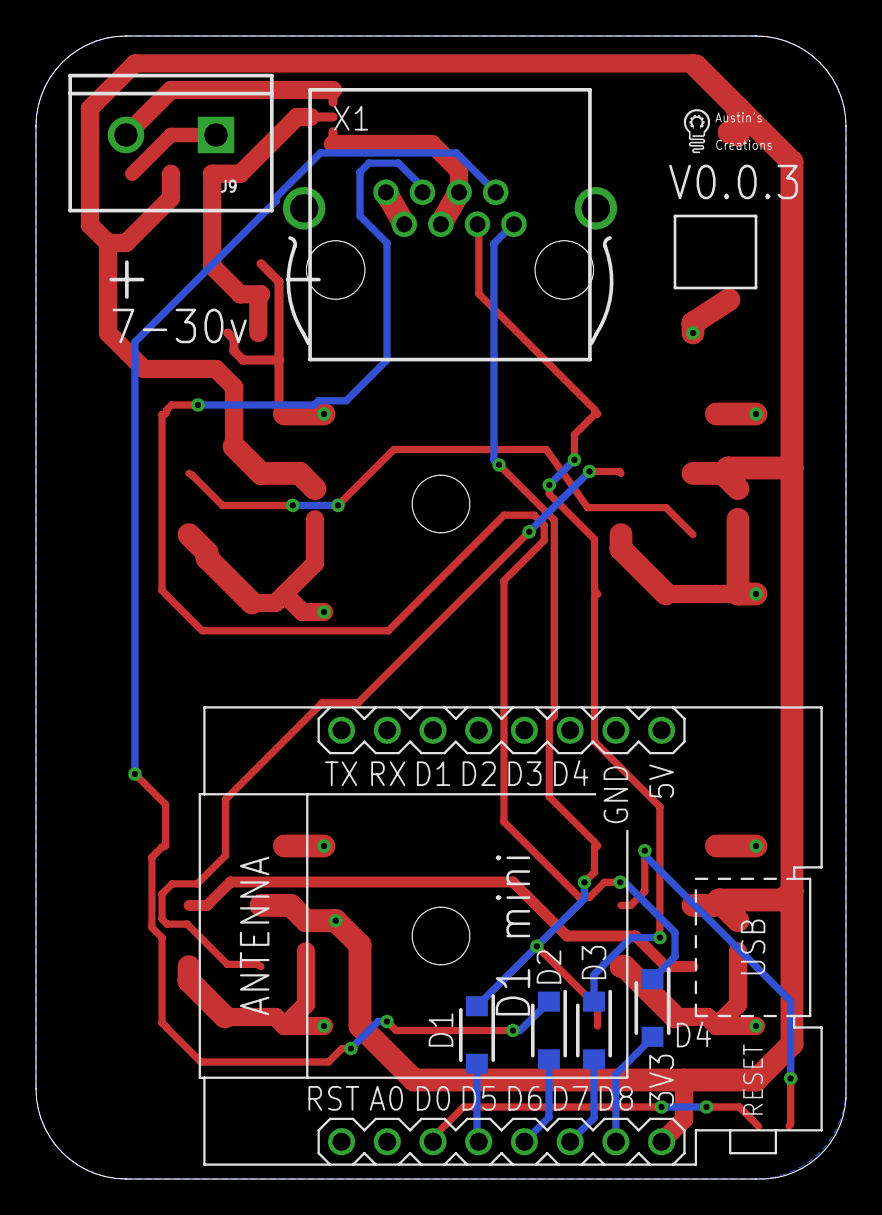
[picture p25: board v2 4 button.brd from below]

Board: 2 copper layers, 45.0 x 63.5 mm, 30 parts (8 on the bottom side), 18 nets.

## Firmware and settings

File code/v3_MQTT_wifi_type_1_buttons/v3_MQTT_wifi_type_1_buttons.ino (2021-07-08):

/* 
 *  2021-07-08 v0.2.0
 *  wifi and mqtt conenction working as of 12:38 2021-04-22
 *  neopixels working 18:11 2021-04-30
 *  
 *
 *  option - set color    (topic = %hostname%/color; payload = led#, R,G,B,W (0-255))
 *  option fade to color  (topic = %hostname%/fade;  payload = led#, R,G,B,W (0-255))
 *  option ring           (topic = %hostname%/ring;  payload = led#, #ON, R,G,B,W (0-255))
 *  option FWD animation  (topic = %hostname%/fwd;   payload = led#, R,G,B,W,R2,G2,B2,W2,  (0-255))
 *  option BWD animation  (topic = %hostname%/bwd;   payload = led#, R,G,B,W,R2,G2,B2,W2,  (0-255))
 *
 *  button press = button # output on topic %hostname%/button
 *  
 *  online status can be found with %hostname%/LWT
 *  
 *  working button code 2021-07-08
 *  buttons and leds are now 1-based to match LSC 2021-07-08
 */

#include <ESP8266WiFi.h>
#include <ESP8266mDNS.h>
#include <PubSubClient.h>             // For MQTT
#include <Adafruit_NeoPixel.h>
#include "config.h"
#include "buttons.h"                  // For button click handling (embedded)

multiButton button = multiButton();
char g_mqtt_message_buffer[64];

WiFiClient espClient;
PubSubClient client(espClient);

Adafruit_NeoPixel strip(LED_COUNT, LED_PIN, LED_TYPE + NEO_KHZ800);

/*
 * stuff below here shouldn't need to be changed
 */

  const char* out_topic = "-";
  const char* out_heart = "-";
  const char* in_topic1 = "-";
  const char* in_topic2 = "-";
  const char* in_topic3 = "-";
  const char* in_topic4 = "-";
  const char* in_topic5 = "-";
  char clientoutput[100];
  char clientoutput2[100];
  char clientinput[100];
  char clientinput2[100];
  char clientinput3[100];
  char clientinput4[100];
  char clientinput5[100];
  char connectphrase[100]; // publishes to 'outTopic' when connected

 
// Initialize color variables
int prevR[buttonamount] = {};
int prevG[buttonamount] = {};
int prevB[buttonamount] = {};
int prevW[buttonamount] = {};

int redVal[buttonamount] = {};
int grnVal[buttonamount] = {}; 
int bluVal[buttonamount] = {};
int whiVal[buttonamount] = {};

int rednew[buttonamount] = {};
int grnnew[buttonamount] = {}; 
int blunew[buttonamount] = {};
int whinew[buttonamount] = {};
int rednew1[buttonamount] = {};
int grnnew1[buttonamount] = {}; 
int blunew1[buttonamount] = {};
int whinew1[buttonamount] = {};

int spot[buttonamount] = {0};
int neo_update[buttonamount] = {false};
int fwd = 0;
int fwd_prev = 0;
int bwd = 3;
int bwd_prev = 3;
int ledmode[(buttonamount+1)] = {0};

int r = 0;
int g = 0;
int b = 0;
int w = 0;
int c = 0;
int R = 0;
int G = 0;
int B = 0;
int W = 0;

int SoffitC;
int SoffitS;
int SoffitR;
int SoffitG;
int SoffitB;
int SoffitW;
int SoffitR1;
int SoffitG1;
int SoffitB1;
int SoffitW1;

unsigned long previousMillis2 = 0;
unsigned long previousMillis3 = 0;

int connected_update = false;

char * getMqttButtonAction(uint8_t state)
{
  // Determine what action we need to publish
  static char action[7];
  switch (state)
  {
    case BUTTON_HOLD_STATE:
      sprintf_P(action, PSTR("HOLD"));
      break;
    case 1:
      sprintf_P(action, PSTR("SINGLE"));
      break;
    case 2:
      sprintf_P(action, PSTR("DOUBLE"));
      break;
    case 3:
      sprintf_P(action, PSTR("TRIPLE"));
      break;
    case 4:
      sprintf_P(action, PSTR("QUAD"));
      break;
    case 5:
      sprintf_P(action, PSTR("PENTA"));
      break;
    default:
      sprintf_P(action, PSTR("ERROR"));
      break;
  }
  return action;
}

void buttonPressed(uint8_t button, uint8_t state)
{
 
  // Determine the port, switch, and button numbers (1-based)
  uint8_t raw_button =  button;
  uint8_t mqtt_button = raw_button + 1;

  if (DEBUG_BUTTONS)
  {
    Serial.print(F("Press detected: "));
    Serial.print(F(" BUTTON: "));
    Serial.print(mqtt_button);
    Serial.print(F(" STATE: "));
    Serial.print(state);
    Serial.print(F(" ACTION: "));
    Serial.println(getMqttButtonAction(state));
  }

  // Publish event to MQTT
  sprintf_P(g_mqtt_message_buffer, PSTR("{\"BUTTON\":%d, \"ACTION\":\"%s\"}"), mqtt_button, getMqttButtonAction(state));
  client.publish(out_topic, g_mqtt_message_buffer);
}

void setup() {

  Serial.begin(SERIAL_BAUD_RATE);
  delay(1000);
//  Serial.println(ESP.getResetReason());
 
  strip.begin();           // INITIALIZE NeoPixel strip object (REQUIRED)
  strip.show();            // Turn OFF all pixels ASAP

  settopics();
  WiFi.hostname(host);
  setup_wifi();
  client.setServer(mqtt_broker, mqtt_port);
  client.setCallback(callback);

 for (uint8_t i = 0; i < buttonamount; i++)
  {
   button.setup(i, buttons[i]);
  }

  button.onButtonPressed(buttonPressed);
}

void loop() {
 if (!client.connected()) {
    reconnect();
  }
   client.loop();
   
   if (connected_update == true){ // if we are conencted to wifi and mqtt go green briefly
      success();
    }

    button.process();


  /*
   * 
   * Control leds from incoming mqtt message
   * 
   */

  ringupdate();

    for (int x = 0; x < buttonamount; x ++){ // check each led
        
        if (ledmode[x] == 5){
          if (fwd != fwd_prev){
          FWDring(x,rednew[x],grnnew[x],blunew[x],whinew[x],rednew1[x],grnnew1[x],blunew1[x],whinew1[x]);
         }
        }
        if (ledmode[x] == 4){
          if (bwd != bwd_prev){
          BWDring(x,rednew[x],grnnew[x],blunew[x],whinew[x],rednew1[x],grnnew1[x],blunew1[x],whinew1[x]);
         }
        }
      if (ledmode[x] == 3){ // fade led
        if (neo_update[x] == true){
          timering(x,spot[x],rednew[x],grnnew[x],blunew[x],whinew[x]);
        }
       }
      if (ledmode[x] == 2){ // fade led
        if (neo_update[x] == true){
          crossfadeRGB(x,rednew[x],grnnew[x],blunew[x],whinew[x]);
        }
       }
      if (ledmode[x] == 1){ // just change the color
        if (neo_update[x] == true){
          colorWipe(x,rednew[x],grnnew[x],blunew[x],whinew[x]);
        }
      }
    }

    fwd_prev = fwd;
    bwd_prev = bwd;

}

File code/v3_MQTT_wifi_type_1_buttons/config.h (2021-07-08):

/* ----------------- General config -------------------------------- */
/* Debugging */
#define DEBUG_BUTTONS          true

/* Serial */
#define SERIAL_BAUD_RATE       115200

/* LED's */
#define LED_PIN                0                    // pin neopixels are connected to -- shouldn't need to be changed
#define LED_COUNT              16                   // number of neopixels
#define LED_TYPE               NEO_GRBW

/* Buttons */
const int buttonamount         = 4;                 // number of buttons connected
int buttons[(buttonamount+1)]  = {14,12,13,4};      // pin button is connected to

/* Variables */
int fadespeed                  = 125;               // speed in micros() for color fade mode
int ringspeed                  = 250;               // speed in millis() for ring animation

/* WIFI */ 
const char* host               = "buttonswitch";    // host name to show on wifi network && mqtt topics
const char* ssid               = "***";
const char* password           = "****";

/* MQTT */
const char*   mqtt_broker      = "192.168.0.54";    // IP address or host name of your MQTT broker
const int     mqtt_port        = 1883;

const char*  mqtt_username     = "****";
const char*  mqtt_password     = "****";

const uint8_t mqtt_lwt_qos     = 0;
const uint8_t mqtt_lwt_retain  = 1;

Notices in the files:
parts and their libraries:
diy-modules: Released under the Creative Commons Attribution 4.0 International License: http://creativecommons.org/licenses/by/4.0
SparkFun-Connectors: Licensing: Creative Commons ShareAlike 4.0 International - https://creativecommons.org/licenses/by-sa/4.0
